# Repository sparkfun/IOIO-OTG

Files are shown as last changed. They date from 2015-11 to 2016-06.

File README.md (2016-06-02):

IOIO-OTG
========

IOIO-OTG

[*IOIO-OTG (DEV-11343)*](https://www.sparkfun.com/products/11343)

The IOIO-OTG is a development board specifically designed for advanced hardware I/O capapbilities to your Android or PC application.
This board also allows the user to leverage USB On-The-Go specification to connect as a host or as an accessory. 

Repository Contents
-------------------
* **/Hardware** - All Eagle design files (.brd, .sch, .STL)
* **/Production** - Test bed files and production panel files

Documentation
--------------

* **[Hookup Guide](https://learn.sparkfun.com/tutorials/ioio-otg-hookup-guide)** - Basic hookup guide for the IOIO-OTG.
* **[SparkFun Fritzing repo](https://github.com/sparkfun/Fritzing_Parts)** - Fritzing diagrams for SparkFun products.
* **[SparkFun 3D Model repo](https://github.com/sparkfun/3D_Models)** - 3D models of SparkFun products. 
* **[SparkFun Graphical Datasheets](https://github.com/sparkfun/Graphical_Datasheets)** -Graphical Datasheets for various SparkFun products.

Product Versions
----------------
* [v22b](https://www.sparkfun.com/products/13613)- Version 2.2b. Currently for sale.
* [v21] (https://www.sparkfun.com/products/retired/12633)- Version 2.1. Retired.

Version History
---------------
* [v2.2b](https://github.com/sparkfun/IOIO-OTG/tree/V_2.2b) - GitHub files v2.2b
* [v2.1](https://github.com/sparkfun/IOIO-OTG/tree/V_2.1) - GitHub files v2.1

License Information
-------------------
This product is _**open source**_! 

Please review the LICENSE.md file for license information. 

If you have any questions or concerns on licensing, please contact techsupport@sparkfun.com.

Distributed as-is; no warranty is given.

- Your friends at SparkFun.

The IOIO is a collaboration with Ytai Ben-Tsvi. You can find his repo [here](https://github.com/ytai/ioio/wiki).

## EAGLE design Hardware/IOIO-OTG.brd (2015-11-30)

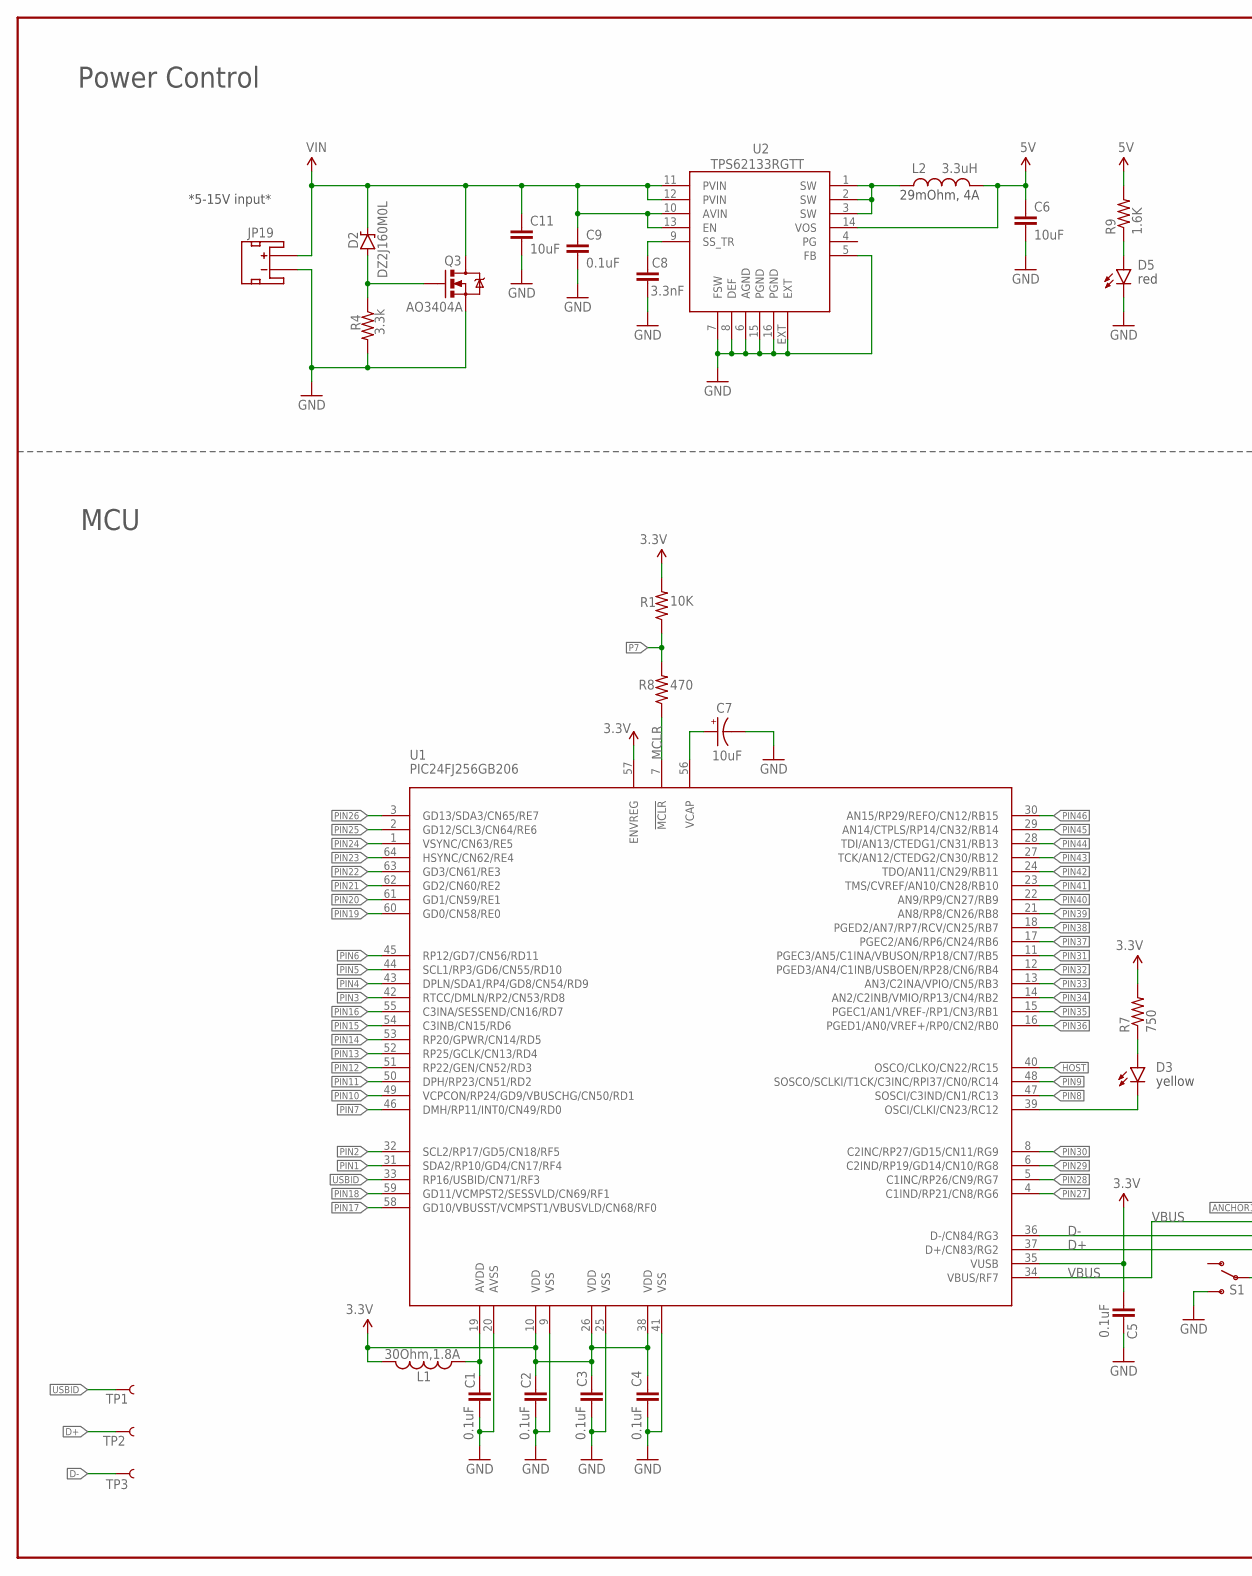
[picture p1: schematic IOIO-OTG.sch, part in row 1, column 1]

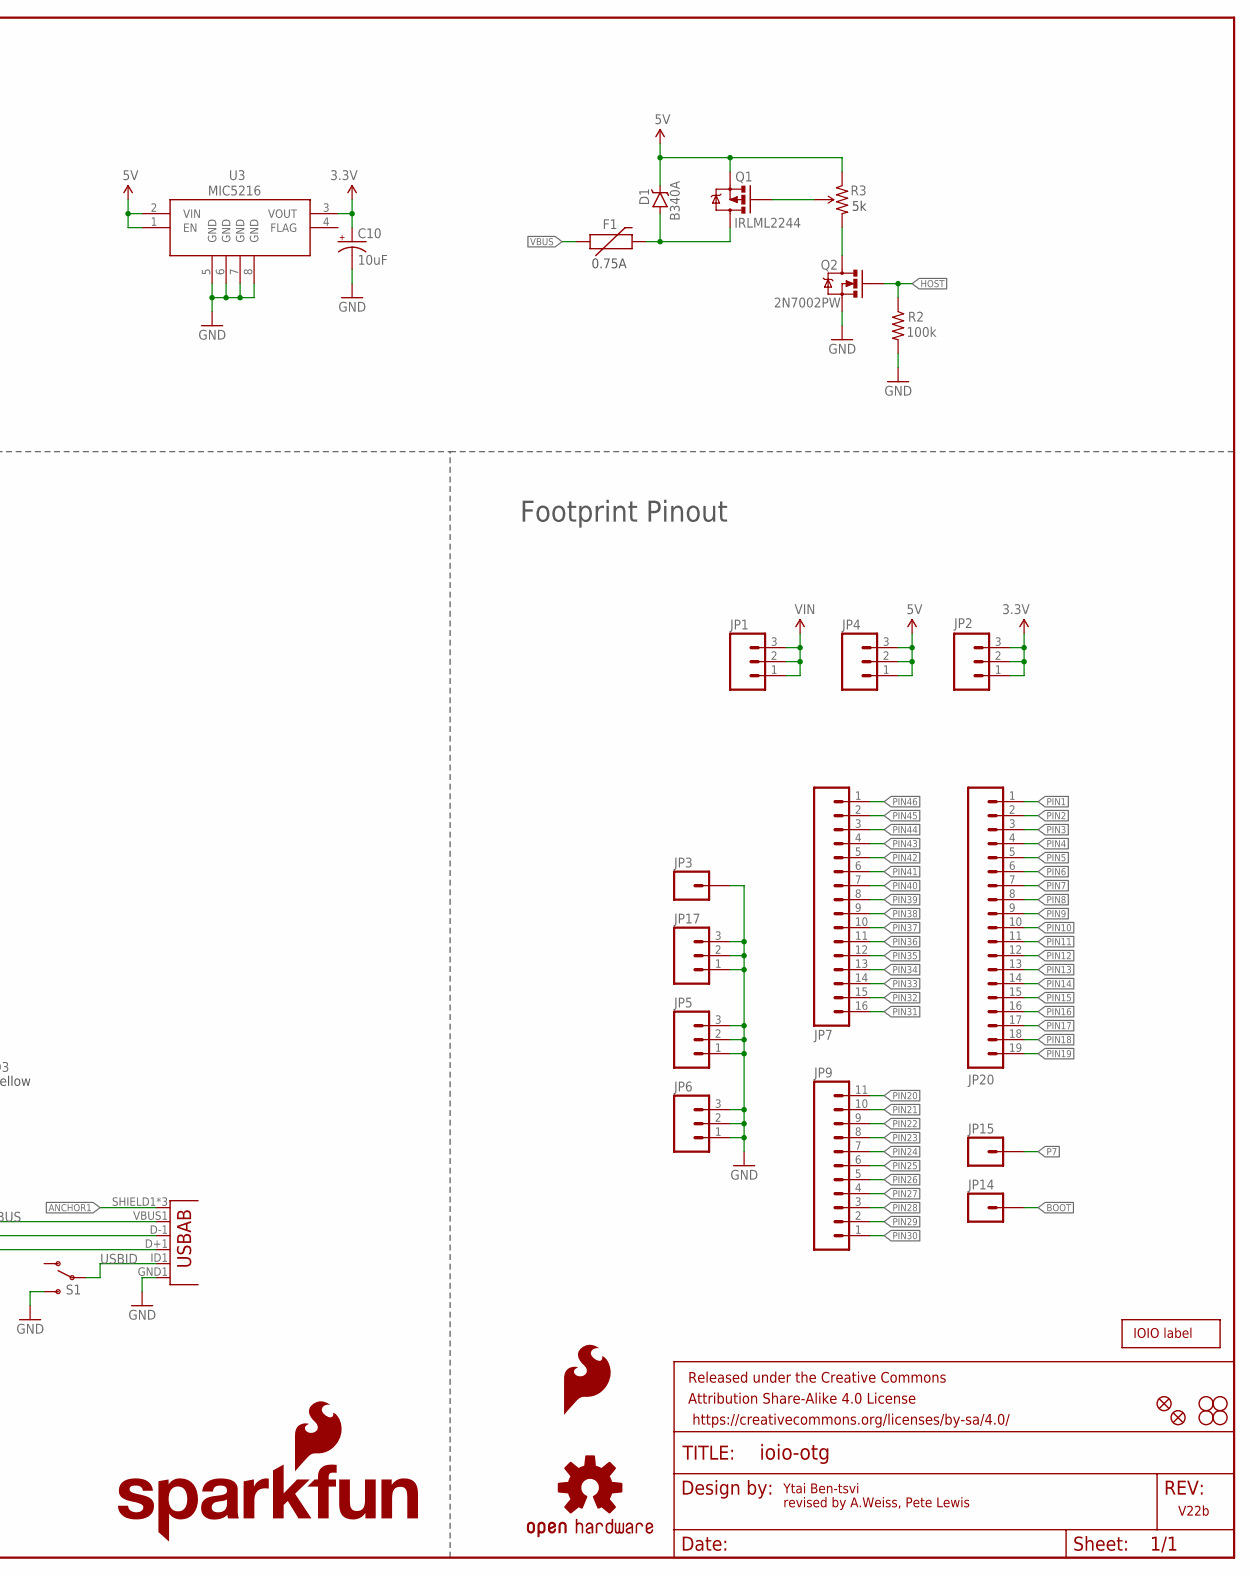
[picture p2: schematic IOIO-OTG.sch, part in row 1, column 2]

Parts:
C1, C2, C3, C4, C5, C9: 0.1uF; 0603-CAP
C6: 10uF; 0805-CAP; PART# LMK212BJ106KG-T
C7: 10uF; EIA3216
C8: 3.3nF; 0603-CAP
C10: 10uF; EIA3216; PART# TAJA106K016RNJ
C11: 10uF; 1210; PART# UMK325C7106MM-T
D1: B340A; SMA-DIODE; PART# B340A
D2: DZ2J160M0L; PANASONIC_SMINI2-F5-B; PART# DZ2J150M0L
D3: Yellow; LED-0603
D5: Red; LED-0603
F1: 0.75A; PTC-1206; PART# 0ZCA0075FF2G
FRAME2: FRAME-LEDGER; CREATIVE_COMMONS
JP1, JP2, JP4, JP5, JP6, JP17: M03PTH; 1X03
JP3, JP14, JP15: M01PTH; 1X01
JP7: M161X16_NO_SILK; 1X16_NO_SILK
JP8, JP16: FIDUCIALUFIDUCIAL; MICRO-FIDUCIAL
JP9: M111X11_NO_SILK; 1X11_NO_SILK
JP10, JP11, JP12, JP13: STAND-OFF
JP19: JST; JST-2-SMD
JP20: M191X19_NO_SILK; 1X19_NO_SILK
JP21: AB MICRO USB; USB-AB-MICRO-SMD_V03
L1: 30Ohm,1.8A; 0603
L2: VLC5045T-3R3N; CR54
LOGO1: OSHW-LOGOS; OSHW-LOGO-S
LOGO2: SFE_LOGO_NAME_FLAME.1_INCH; SFE_LOGO_NAME_FLAME_.1
LOGO3: SFE_LOGO_FLAME.1_INCH; SFE_LOGO_FLAME_.1
Q1: IRLML2244; SOT23-3
Q2: 2N7002PW; SOT323; PART# 2N7002PW
Q3: MOSFET-NCHANNELAO3404A; SOT23-3; PART# AO3404A
R1: 10K; 0603-RES
R2: 100k; 0603-RES
R3: TS53YL502MR10; TRIMPOT_5MM; PART# TS53YL502MR10
R4: 3.3k; 0603-RES
R7: 750; 0603-RES
R8: 470; 0603-RES
R9: 1.6K; 0603-RES
S1: SWITCH_SPDT; KPS-1290
TP1, TP2, TP3: TEST-POINT3; PAD.03X.03
U1: PIC24FJ256GB206; PIC24FXXX_TQFP64
U2: TPS62133RGTT; QFN16-3X3MM_1:1_V03
U3: MIC5216; MSOP8
U$6: IOIO-OTG; IOIO-OTG-COPPER-EXPOSED

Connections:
3.3V: C2.1, C3.1, C4.1, C5.1, C10.A (+), JP2.1, JP2.2, JP2.3, L1.2, R1.2, R7.2, U1.10 (VDD), U1.26 (VDD), U1.35 (VUSB), U1.38 (VDD), U1.57 (ENVREG), U3.3 (VOUT)
5V: C6.1, D1.C, JP4.1, JP4.2, JP4.3, L2.P$2 (2), Q1.2 (S), R3.A (CCW), R9.2, U2.14 (VOS), U3.1 (EN), U3.2 (VIN)
ANCHOR1: JP21.SHIELD1 (SHIELD), JP21.SHIELD2 (SHIELD), JP21.SHIELD3 (SHIELD)
BOOT: D3.C, JP14.1, U1.39 (OSCI/CLKI/CN23/RC12)
D+: JP21.D+1 (D+), TP2.P$1, U1.37 (D+/CN83/RG2)
D-: JP21.D-1 (D-), TP3.P$1, U1.36 (D-/CN84/RG3)
GND: C1.2, C2.2, C3.2, C4.2, C5.2, C6.2, C7.C (-), C8.2, C9.2, C10.C (-), C11.2, D5.C, JP3.1, JP5.1, JP5.2, JP5.3, JP6.1, JP6.2, JP6.3, JP17.1, JP17.2, JP17.3, JP19.1 (-), JP21.GND1 (GND), Q2.2 (S), Q3.2 (S), R2.2, R4.2, S1.S, U1.9 (VSS), U1.20 (AVSS), U1.25 (VSS), U1.41 (VSS), U2.5 (FB), U2.6 (AGND), U2.7 (FSW), U2.8 (DEF), U2.15 (PGND), U2.16 (PGND), U2.EXT, U3.5 (GND), U3.6 (GND), U3.7 (GND), U3.8 (GND)
HOST: Q2.1 (G), R2.1, U1.40 (OSCO/CLKO/CN22/RC15)
MCLR: R8.1, U1.7 (!MCLR)
unnamed: Q1.1 (G), R3.B (WIPER)
unnamed: D3.A, R7.1
unnamed: D5.A, R9.1
unnamed: D1.A, F1.2, Q1.3 (D)
unnamed: C7.A (+), U1.56 (VCAP)
unnamed: L2.P$1 (1), U2.1 (SW), U2.2 (SW), U2.3 (SW)
unnamed: C8.1, U2.9 (SS_TR)
unnamed: Q2.3 (D), R3.C (CW)
unnamed: C1.1, L1.1, U1.19 (AVDD)
unnamed: D2.A, Q3.1 (G), R4.1
P7: JP15.1, R1.1, R8.2
PIN1: JP20.1, U1.31 (SDA2/RP10/GD4/CN17/RF4)
PIN2: JP20.2, U1.32 (SCL2/RP17/GD5/CN18/RF5)
PIN3: JP20.3, U1.42 (RTCC/DMLN/RP2/CN53/RD8)
PIN4: JP20.4, U1.43 (DPLN/SDA1/RP4/GD8/CN54/RD9)
PIN5: JP20.5, U1.44 (SCL1/RP3/GD6/CN55/RD10)
PIN6: JP20.6, U1.45 (RP12/GD7/CN56/RD11)
PIN7: JP20.7, U1.46 (DMH/RP11/INT0/CN49/RD0)
PIN8: JP20.8, U1.47 (SOSCI/C3IND/CN1/RC13)
PIN9: JP20.9, U1.48 (SOSCO/SCLKI/T1CK/C3INC/RPI37/CN0/RC14)
PIN10: JP20.10, U1.49 (VCPCON/RP24/GD9/VBUSCHG/CN50/RD1)
PIN11: JP20.11, U1.50 (DPH/RP23/CN51/RD2)
PIN12: JP20.12, U1.51 (RP22/GEN/CN52/RD3)
PIN13: JP20.13, U1.52 (RP25/GCLK/CN13/RD4)
PIN14: JP20.14, U1.53 (RP20/GPWR/CN14/RD5)
PIN15: JP20.15, U1.54 (C3INB/CN15/RD6)
PIN16: JP20.16, U1.55 (C3INA/SESSEND/CN16/RD7)
PIN17: JP20.17, U1.58 (GD10/VBUSST/VCMPST1/VBUSVLD/CN68/RF0)
PIN18: JP20.18, U1.59 (GD11/VCMPST2/SESSVLD/CN69/RF1)
PIN19: JP20.19, U1.60 (GD0/CN58/RE0)
PIN20: JP9.11, U1.61 (GD1/CN59/RE1)
PIN21: JP9.10, U1.62 (GD2/CN60/RE2)
PIN22: JP9.9, U1.63 (GD3/CN61/RE3)
PIN23: JP9.8, U1.64 (HSYNC/CN62/RE4)
PIN24: JP9.7, U1.1 (VSYNC/CN63/RE5)
PIN25: JP9.6, U1.2 (GD12/SCL3/CN64/RE6)
PIN26: JP9.5, U1.3 (GD13/SDA3/CN65/RE7)
PIN27: JP9.4, U1.4 (C1IND/RP21/CN8/RG6)
PIN28: JP9.3, U1.5 (C1INC/RP26/CN9/RG7)
PIN29: JP9.2, U1.6 (C2IND/RP19/GD14/CN10/RG8)
PIN30: JP9.1, U1.8 (C2INC/RP27/GD15/CN11/RG9)
PIN31: JP7.16, U1.11 (PGEC3/AN5/C1INA/VBUSON/RP18/CN7/RB5)
PIN32: JP7.15, U1.12 (PGED3/AN4/C1INB/USBOEN/RP28/CN6/RB4)
PIN33: JP7.14, U1.13 (AN3/C2INA/VPIO/CN5/RB3)
PIN34: JP7.13, U1.14 (AN2/C2INB/VMIO/RP13/CN4/RB2)
PIN35: JP7.12, U1.15 (PGEC1/AN1/VREF-/RP1/CN3/RB1)
PIN36: JP7.11, U1.16 (PGED1/AN0/VREF+/RP0/CN2/RB0)
PIN37: JP7.10, U1.17 (PGEC2/AN6/RP6/CN24/RB6)
PIN38: JP7.9, U1.18 (PGED2/AN7/RP7/RCV/CN25/RB7)
PIN39: JP7.8, U1.21 (AN8/RP8/CN26/RB8)
PIN40: JP7.7, U1.22 (AN9/RP9/CN27/RB9)
PIN41: JP7.6, U1.23 (TMS/CVREF/AN10/CN28/RB10)
PIN42: JP7.5, U1.24 (TDO/AN11/CN29/RB11)
PIN43: JP7.4, U1.27 (TCK/AN12/CTEDG2/CN30/RB12)
PIN44: JP7.3, U1.28 (TDI/AN13/CTEDG1/CN31/RB13)
PIN45: JP7.2, U1.29 (AN14/CTPLS/RP14/CN32/RB14)
PIN46: JP7.1, U1.30 (AN15/RP29/REFO/CN12/RB15)
USBID: JP21.ID1 (USBID), S1.P, TP1.P$1, U1.33 (RP16/USBID/CN71/RF3)
VBUS: F1.1, JP21.VBUS1 (VBUS), U1.34 (VBUS/RF7)
VIN: C9.1, C11.1, D2.C, JP1.1, JP1.2, JP1.3, JP19.2 (+), Q3.3 (D), U2.10 (AVIN), U2.11 (PVIN), U2.12 (PVIN), U2.13 (EN)

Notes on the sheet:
Ytai Ben-tsvi
revised by A.Weiss, Pete Lewis
*5-15V input*
yellow
red
0.75A
29mOhm, 4A
Footprint Pinout
Power Control
MCU
V22b
DZ2J160M0L
AO3404A
2N7002PW
IRLML2244
B340A

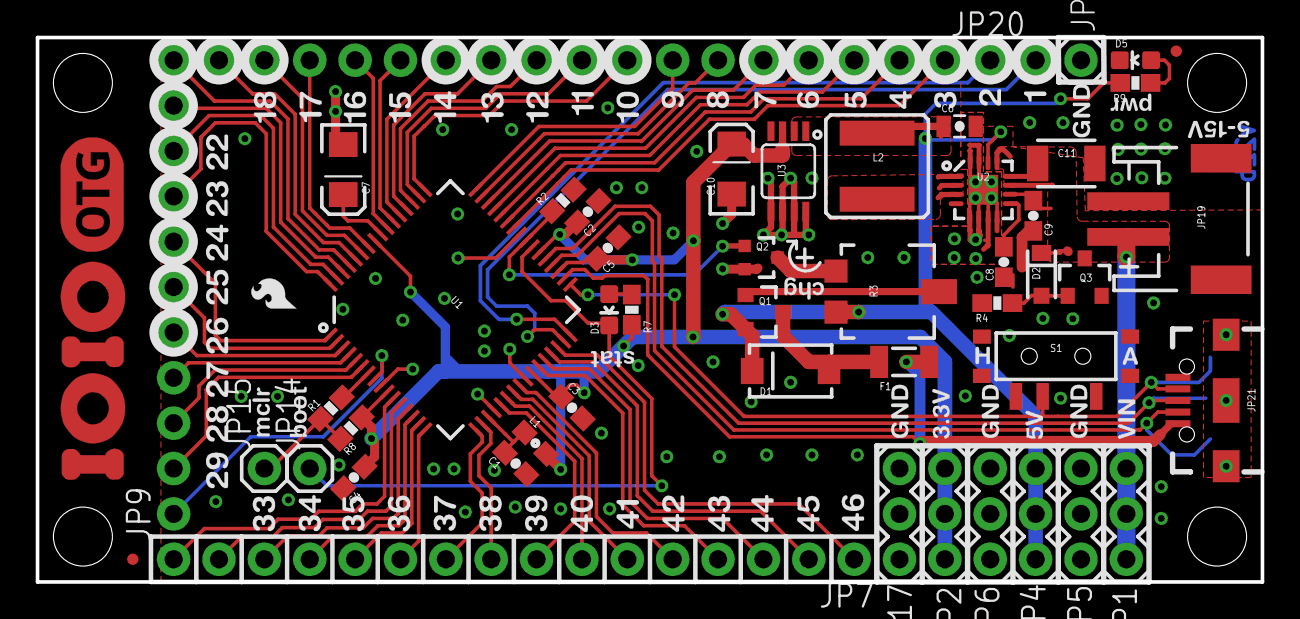
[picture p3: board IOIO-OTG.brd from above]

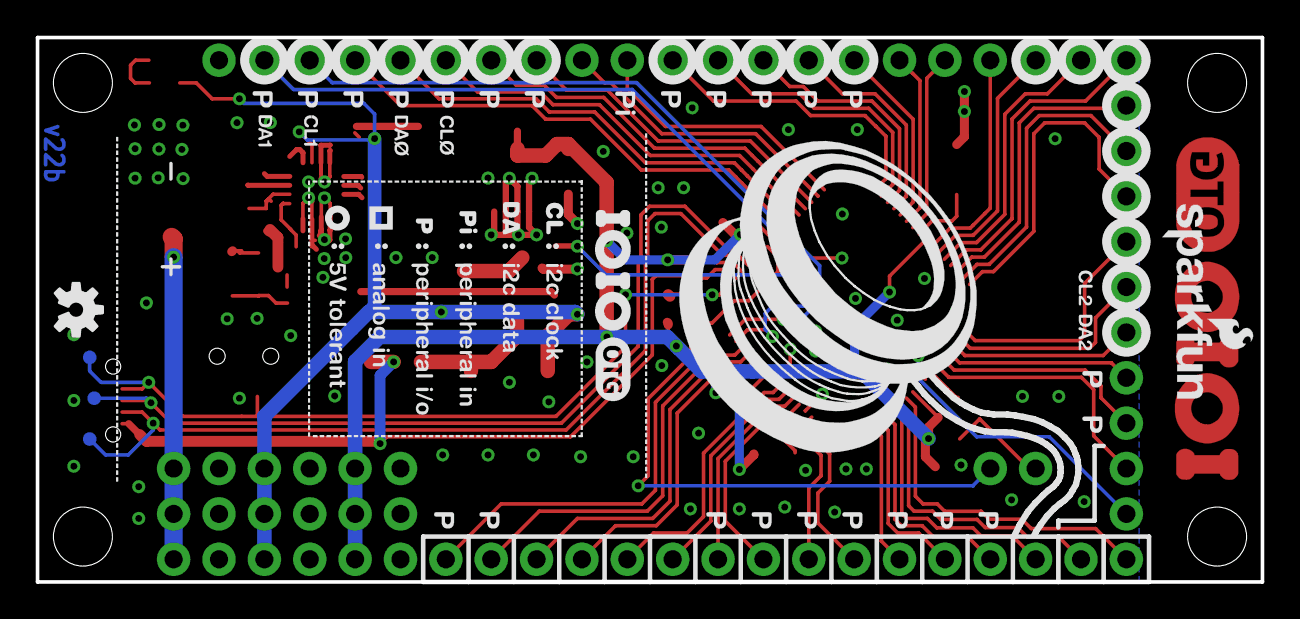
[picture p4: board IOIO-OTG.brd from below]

Board: 2 copper layers, 68.6 x 30.5 mm, 60 parts (5 on the bottom side), 69 nets.

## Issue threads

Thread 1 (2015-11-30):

Issues from checklist review 11/30

SFE-KADE, 2015-11-30:
1.) D1, D2, Q1, Q2, Q3 need value in schematic.

2.) Looks like the design is still using the old sparkfun 2-layer DRU

Thanks!

lewispg228, 2015-11-30:
Thanks Kade!

Two things to note:

1) I added in text objects on the value layer separate from device. I will discuss at the DFM committee this week whether it will officially be standard to include in the symbol at the library level. But for this design to move forward, I'd like to just leave them as separate text objects floating in the wild.

2) When I moved to the TIGHT dru, I noticed that this also decreased the annular rings on vias, so I also bumped the vias up to 15 mil (they were previously 12 mil) Due to the tighter restring in the TIGHT dru each via actually ended up having a smaller overall footprint, and so it didn't necessitate moving anything and/or re-routing.

Please check it out and let me know.

Thanks!

SFE-KADE, 2015-11-30:
Looks good. Thanks!

Closed 2015-11-30.

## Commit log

2010-10-31 create repository
    [IOIO.brd, IOIO.sch]
2010-12-16 Hardware V11
    [IOIO.brd, IOIO.sch]
2011-01-20 first version of V12 from sparkfun
    [IOIO-v12.brd, IOIO-v12.sch]
2011-01-21 board labeling fixes
    [IOIO-v12.brd, IOIO-v12.sch, IOIO.brd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]
2011-01-21 fixed mirrored bottom silk
    [IOIO.brd]
2011-01-21 changed bottom silk design
    [IOIO.brd, IOIO.sch]
2011-03-08 fixes to silk screen.
    [IOIO.brd]
2011-03-08 added switching vreg. moved reset pin to .1" grid
    [IOIO.brd, IOIO.sch]
2011-03-11 new hardware version. added switching vreg. grid-aligned reset pin. current limiting trimmer.
    [IOIO.brd, IOIO.sch]
2011-04-07 hardware v1.4
    [IOIO.brd, IOIO.sch]
2011-04-07 hardware v1.5
    [IOIO.brd, IOIO.sch]
2012-02-19 Fix CRLF
    [IOIO.brd, IOIO.sch]
2012-02-29 fix files damaged by crlf mess
    [IOIO.sch]
2013-01-18 Added IOIO-OTG EAGLE files.
    [IOIO-OTG.brd, IOIO-OTG.sch]
2013-08-01 Initial commit - gitignore, .brd and .sch
    pulled from KENTRO (v20)
    [IOIO-OTG.brd, IOIO-OTG.sch]
2013-08-12 Heavy Revision
    (1) Created and added a new 1:1 FP for the TPS... IC
    (2) Routed all traces directly out from the TPS... IC
    (3) 0402 --> 0603
    (4) Created and added a new FP for a new microAB USB connector, this new
    FP is based off of the data-sheet for the new USB microAB that should
    have guiding bosses (very much trial right now).
    [IOIO-OTG.brd, IOIO-OTG.sch]
2013-08-14 More changes:
    -removed test-points from below the microAB
    -Moved "PWR" LED and RES out just a bit more to clear headers on the OTG
    w/ Headers
    -Created and added a new TRIMPOT FP per Bob's request
    -Added T-Stop around the PIC to allow Tyler T. to be able to inspect the
    PIC with the AOI
    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
    [IOIO-OTG.brd, IOIO-OTG.sch]
2013-08-19 changed trimpot silk
    [IOIO-OTG.brd]
2013-08-19 Added VBUS test-point and Tstop around VREG
    [IOIO-OTG.brd, IOIO-OTG.sch]
2013-08-19 fixed inconsistency between BRD and SCH
    [IOIO-OTG.brd]
2013-08-22 Consistency fixes
    [IOIO-OTG.brd, IOIO-OTG.sch]
2013-08-22 Final 6.5.0 inconsistency fixes
    [IOIO-OTG.brd, IOIO-OTG.sch]
2013-09-11 Added test-points
    3 new test-points:
    D+
    D-
    USBID
    [IOIO-OTG.brd, IOIO-OTG.sch]
2013-09-11 Slight test-point position change
    [IOIO-OTG.brd, IOIO-OTG.sch]
2013-09-11 Added vias below TPS IC for better GND flow
    [IOIO-OTG.brd]
2013-09-11 Changed positions of Test-Points
    [IOIO-OTG.brd]
2014-12-03 hardware: Fixed brd file to make annotation happy
    [IOIO-OTG.brd]
2015-04-09 BRD/SCH from 3/11, includes new power protection
    [IOIO-OTG.brd, IOIO-OTG.sch]
2015-04-09 Switch USB connector to part with mounting bosses
    Also included an anchor polygon to strengthen mounting pads.
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2015-04-09 Moved R1, R8, C4 to proper 0603 packages
    All three components had to move slightly. This will require updating
    their x/y coordinates.
    [IOIO-OTG.sch]
2015-04-09 Moved C1 and L1 to proper 0603 packages
    moved X/Y coordinates
    [IOIO-OTG.brd, IOIO-OTG.sch]
2015-04-09 Moved C3 to proper 0603 package
    moved X/Y coordinate
    [IOIO-OTG.brd, IOIO-OTG.sch]
2015-04-10 All remaining 0402 passives bumped to 0603
    all components had slight shift in X/Y coordinates. Components near the
    TPS6124 also requires some shifting. Included an "original" and "moved
    to 0603" screen shot of design for review.
    [IOIO-OTG.brd, IOIO-OTG.sch]
2015-04-10 Moved to v22 in sch/copper, updated frame in SCH
    [IOIO-OTG.brd, IOIO-OTG.sch]
2015-04-10 Restored back to 1.6K and 750 ohm LED resistors
    [IOIO-OTG.brd, IOIO-OTG.sch]
2015-04-20 Clearance errors
    Set DRC to 7 mil (our standard is 8, but this design is really tight).
    very slight shifting of some traces to fix clearance errors.
    [IOIO-OTG.brd]
2015-04-20 updated pic24 IC device, add tstop between legs
    The white solder mask in between the legs on the IC was causing the AOI
    to throw tons of false calls. removing the mask solves the issue.
    [IOIO-OTG.brd, IOIO-OTG.sch]
2015-04-20 moved to SFE logo
    both mini flame on top, and backside name/flame
    [IOIO-OTG.brd, IOIO-OTG.sch]
2015-04-20 DFM routing for TPS chip
    -added tRestrict to separate pads on TPS chip.
    -changed copper to v22b
    [IOIO-OTG.sch]
2015-04-20 v22b in copper and sch
    [IOIO-OTG.brd]
2015-04-22 Schematic Cleanup
    flags, spacing, revisor
    [IOIO-OTG.brd, IOIO-OTG.sch]
2015-04-23 swapping out devices to include PROD_IDs
    [IOIO-OTG.brd, IOIO-OTG.sch]
2015-04-23 more PROD_IDs
    [IOIO-OTG.brd, IOIO-OTG.sch]
2015-04-24 Package update on D2 (zener) and PROD_IDs
    Had to scoot upwards on most of the power circuit components to make
    space for the correct package size on the zener.
    All PROD_IDs done.
    [IOIO-OTG.brd, IOIO-OTG.sch]
2015-04-24 Schematic Cleanup
    [IOIO-OTG.brd, IOIO-OTG.sch]
2015-04-27 updated to vector outlines on ioio copper logo
    [IOIO-OTG.brd, IOIO-OTG.sch]
2015-04-27 approving drc width erros on copper logo
    [IOIO-OTG.brd]
2015-04-27 changing some of the silk over to vectors
    -dashed lines on bplace
    -charge current arrow and "+"
    [IOIO-OTG.brd]
2015-04-27 Bottom silk logo to vector
    also moved bstop star to vector
    [IOIO-OTG.brd]
2015-04-27 Staking vias under USB connector
    Note, had to move test point 3
    [IOIO-OTG.brd]
2015-04-27 ensuring all parts have name/value in board file
    Also arranged them nicely for assembly sheet
    [IOIO-OTG.brd, IOIO-OTG.sch]
2015-04-27 cleaned up measures
    [IOIO-OTG.brd]
2015-04-27 updated polarity and outline silk on some parts
    pic24, tps, trimpot, switch
    [IOIO-OTG.brd, IOIO-OTG.sch]
2015-04-27 nudged 'stat' led silk to avoid via
    [IOIO-OTG.brd]
2015-04-29 4-way junctions in sch
    [IOIO-OTG.sch]
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2015-11-25 Adding in hardware changes from Pete
    [IOIO-OTG.brd, IOIO-OTG.sch, IOIO.brd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]
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2015-11-30 Value text object to sch for D1, D2, Q1, Q2, Q3
    I used part #s for values (rather than the "values") for these
    components. This is to ensure production (and users) will know when they
    are a different component, when looking at the schematic. Note they are
    text objects living in the wild, and not actually part of the device in
    the library. Although, the values are inside the properties for each
    device as well.
    [IOIO-OTG.sch]
2015-11-30 switched to "TIGHT" DRU, bumped vias up to 15 mil
    Note, when I moved to the TIGHT DRU the restring for vias is set to 7
    mil (this makes for a tighter annular ring). The previous DRU settings
    had the restring set at 10 mil, and all of the vias were 12 mil drills.
    When I changed to a 7 mil restring and a 15 mil drill, the vias were
    still a smaller footprint than in the original. So ultimately, this
    didn't necessitate any component moving or trace re-routing.
    [IOIO-OTG.brd]
2016-06-02 Removing old files, adding license and .git files, updating README with product and tutorial links
    [IOIO.brd, IOIO.sch]

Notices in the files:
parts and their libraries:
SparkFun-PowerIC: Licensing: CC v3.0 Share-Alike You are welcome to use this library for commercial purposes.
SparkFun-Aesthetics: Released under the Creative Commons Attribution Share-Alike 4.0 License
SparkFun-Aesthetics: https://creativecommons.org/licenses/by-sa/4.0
